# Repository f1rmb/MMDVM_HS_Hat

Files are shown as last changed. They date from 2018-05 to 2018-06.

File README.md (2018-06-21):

# MMDVM_HS_Hat
MMDVM_HS Hat for the Raspberry Pi (Zero)

This project provides a Raspberry Pi Hat for the [MMDVM_HS Hotspot](https://github.com/juribeparada/MMDVM_HS). It was designed for the Raspberry Pi Zero, but should work on any other Pi with the Hat interface. 

First revisions of the board have been built successfully!

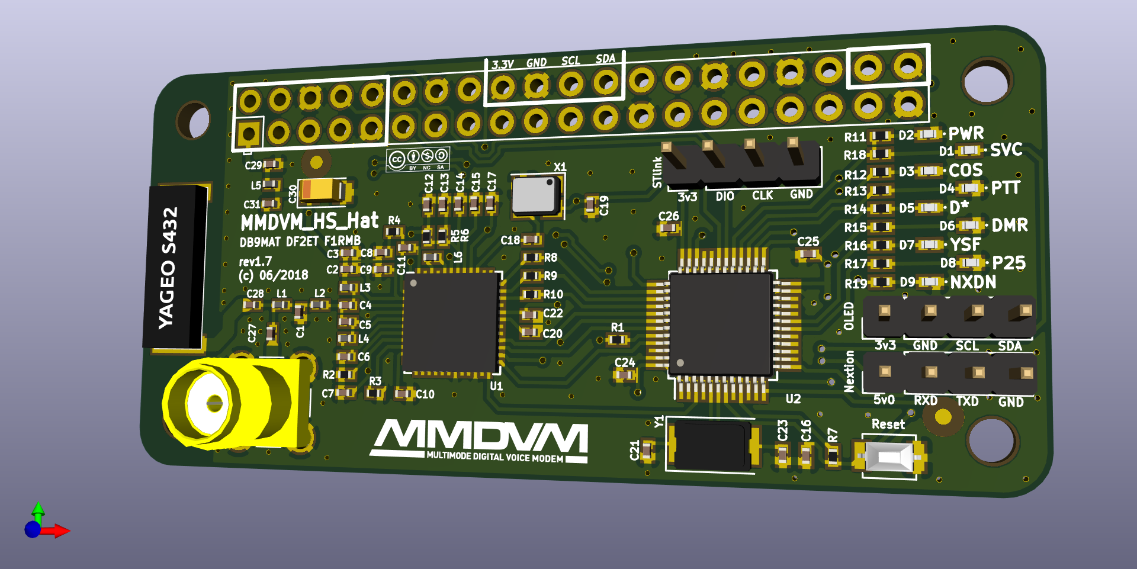
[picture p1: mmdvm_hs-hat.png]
PCB


The PCB is designed in KiCad and the necessary libraries are included. The supplied Gerber files can be used to order PCBs, for example at Elecrow or DirtyPCBs. The board's dimensions are 65x30mm.

__WARNING__
This fork was designed with KiCad 5 RC version (aka development build), opening the PCB file with KiCad 4 will simply fail.

You can order 3 beautiful, purple Revision 1.2 PCBs for $15 at [OSHPark](https://oshpark.com/shared_projects/WaiMw5XE)! 

## 3D printed Cases

Case

Thanks to Toufik, F0DEI we added the ~~sources~~ STL files for a shiny case that you can print with your 3D printer. It may require a little upscaling depending on your printer model. It can carry a Raspberry Pi Zero (W) with MMDVM_HS_Hat (SMA) on top.

<br>
There are also the enclosures, designed by myself, available here https://github.com/f1rmb/MMDVM_HS_Hat-Enclosure

CaseRMB

## Revisions
### Revision 0
This was the first released version that still contains a couple of errors. There is a trace missing between L1 and C1 that needs to be fixed with a small blob of solder or magnet wire. Otherwise the RF connector is not connected to the ADF7021. The GND side of C20 and C22 is not connected to the rest of the board's GND, this needs to be fixed with a little wire to any other GND. CE is connected directly to +3.3V which disallows mode scanning to work. If you just use one mode this is fine, otherwise the connection to the CE pin has to be cut and connected to PC14 on the STM32.

Earlier schematics showed C14 as 1uF. This is wrong and needs to be replaced with 1nF, otherwise the ADF7021 will neither receive nor transmit properly.

With these changes, you can build a fully working MMDVM_HS with the old revision 0 boards

### Revision 1
These boards have "Revision 1" written on them. All bugs found in revision 0 are fixed in this version. Apart from that, the STM32's BOOT0 and RESET pins are connected to GPIOs of the Raspberry Pi. This way, flashing should be possible without manually jumpering BOOT0 and triggering a reset.

Component placement did not change between revisions 0 and 1, therefore any stencils for revision 0 should work for revision 1 boards, too.

### Revision 1.1
Rewired 3v3 line for Nextion display connector to 5v0. Added SERVICE LED for visual heartbeat. Fixed improper labelling on P25 and YSF LEDs. Due to added LEDs this revision requires a new stencil.

### Revision 1.2
This Revision adds support for an optional AN1603-443 ceramic antenna. Insert C27 or C28, depending on what kind of antenna you want to use.

### Revision 1.3
The boot jumper was removed and the STlink header moved to its position. This gave space for another 4-pin header allowing to connect I²C OLED displays. No new stencil needed

### Revision 1.4
The SVC LED has been rotated and thus aligned to the layout of all other LEDs. The RainSun ceramic antenna has been replaced by a model that can be ordered at Mouser. DC line filtering has been added to 3v3 line.

### Revision 1.5
A fith mode LED has been added to the board to show NXDN activity. The two pin headers moved downwards a little. The rev1.4 stencil can be re-used if you manually add solder paste to R19 and D9 afterwards.

### Revision 1.6
Inner RX/TX pins of Nextion connector have been swapped. External VCO inductor L6 was added. This is optional for VHF use. D-Star and DMR LEDs were swapped to flash LEDs in proper scan order :).

### Revision 1.7
I will add the change list later, once the first PCB is assembled and tested :-D (PCB are on their way).

## BOM
* All necessary parts for the Revision 1.1 board can be ordered at Mouser using the following [shopping cart](http://www.mouser.com/ProjectManager/ProjectDetail.aspx?AccessID=780b8eac44)
* All necessary parts for the Revision 1.2 board can be ordered at Mouser using the following [shopping cart](http://www.mouser.com/ProjectManager/ProjectDetail.aspx?AccessID=035e777242)
* There is also a light version of revision 1.2 without the reset switch, 2.54mm headers and SMA connector [Link](http://www.mouser.com/ProjectManager/ProjectDetail.aspx?AccessID=3f7d0256e1)
* The parts for Revision 1.3 board are in this [Mouser cart](http://www.mouser.com/ProjectManager/ProjectDetail.aspx?AccessID=250d76339b) and the light version is [here](http://www.mouser.com/ProjectManager/ProjectDetail.aspx?AccessID=2d533ac53d)
* [Mouser project](http://www.mouser.com/ProjectManager/ProjectDetail.aspx?AccessID=5cab954f40) for MMDVM_HS_Hat revision 1.4
* There is another [Mouser cart for rev 1.5](https://www.mouser.com/ProjectManager/ProjectDetail.aspx?AccessID=5a3e4ae018).
* This is the [rev1.6 cart](https://www.mouser.com/ProjectManager/ProjectDetail.aspx?AccessID=48302f4221) and its [light version](https://www.mouser.com/ProjectManager/ProjectDetail.aspx?AccessID=ac888de33a).
* And this is the [Mouser cart for rev1.7](https://www.mouser.fr/ProjectManager/ProjectDetail.aspx?AccessID=95F1FF1BD5).

Please note that the onboard ceramic antenna is not supplied by Mouser and therefore missing in the carts for revisions up to 1.3.

Either the ADF7021 or the ADF7021-N can be used. Define the proper version in the firmware!

## Firmware Installation

### Compile and upload manually

For specific details about the firmware installation, check [these](https://github.com/juribeparada/MMDVM_HS#build-de-firmware-and-upload-to-zumspot-rpi) instructions. The process is similar to the installation on the ZumSpot Pi. 

Enable the following settings in Config.h:

    #define MMDVM_HS_HAT_REV12
    #define ENABLE_ADF7021
    #define ADF7021_14_7456
    #define STM32_USART1_HOST
    #define ENABLE_SCAN_MODE

Build the firmware:

    make

And finally upload the firmware to the MMDVM_HS_Hat:

    sudo make mmdvm_hs_hat

### Update within Pi-Star

Andy, MW0MWZ was so kind as to add a script which allows for updating the firmware of the MMDVM_HS_Hat within the running Pi-Star system. It uses the pre-compiled binaries from Andy's (CA6JAU) github repository. The update can be done with:

```
$ pistar-zumspotflash hs_hat
```

on the command line.

## Accessoires

* A case for the #MMDVM_HS_Hat can be found at amazon: [Case](https://www.amazon.de/Hochwertiges-schwarzes-auml-uuml-Raspberry/dp/B01FHDXNNU)

* An OLED display also to be found at amazon: [Display](https://www.amazon.de/dp/B01M9JVYIS/ref=cm_sw_r_wa_api_RmZ9zb01APZTV)

## License
This project is released under the Creative Commons Attribution-NonCommercial-ShareAlike 3.0 (CC-BY-NC-SA 3.0, https://creativecommons.org/licenses/by-nc-sa/3.0/) license. You may edit and share it as you like, as long as credit is given and the license is not changed. You can build as many boards for you and your friends as you like and you can even sell it to them to cover your costs, **however it is strictly forbidden to turn this into a commercial product! You are not allowed to build and sell these boards for profit!**

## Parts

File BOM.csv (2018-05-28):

Source: | /home/caudanie/Documents/KiCadProjects/MMDVM_HS_Hat/mmdvm_hs-hat.sch
Date: | Mon 28 May 2018 01:47:52 PM CEST
Tool: | Eeschema 5.0.0-rc2-unknown-da66005~65~ubuntu16.04.1
Generator: | /usr/lib/x86_64-linux-gnu/kicad/plugins/bom_csv_grouped_by_value.py
Component Count: | 76
Individual Components:
Item | Qty | Reference(s) | Value | LibPart | Footprint | Datasheet | MFR | MPN | SPN | SPR | SPURL
 |  | AE1 | CERAMIC_ANTENNA | mmdvm_hs-hat-rescue:Antenna_Dipole-RESCUE-mmdvm_hs-hat | MMDVM:ANT1204 | http://www.mouser.com/ds/2/447/An_SMD_UHF_433_1204_0-595178.pdf | Yageo | ANT1204F002R0433A | 603-ANT1204F002R0433 | Mouser
 |  | C1 | 6p8 | mmdvm_hs-hat-rescue:C-RESCUE-mmdvm_hs-hat | Capacitor_SMD:C_0402_1005Metric | http://www.mouser.com/ds/2/281/c02e-2905.pdf | Murata Electronics | GJM1555C1H6R8BB01D | 81-GJM1555C1H6R8BB1D | Mouser
 |  | C2 | 10n | mmdvm_hs-hat-rescue:C-RESCUE-mmdvm_hs-hat | Capacitor_SMD:C_0402_1005Metric | http://www.mouser.com/ds/2/427/vjw1bcbascomseries-223529.pdf | Vishay / Vitramon | VJ0402Y103KXJCW1BC | 77-VJ0402Y103KXJCBC | Mouser
 |  | C3 | 220p | mmdvm_hs-hat-rescue:C-RESCUE-mmdvm_hs-hat | Capacitor_SMD:C_0402_1005Metric | http://www.mouser.com/ds/2/281/c02e-2905.pdf | Murata Electronics | GRM1555C1H221JA01D | 81-GRM1555C1H221JA01 | Mouser
 |  | C4 | 10p | mmdvm_hs-hat-rescue:C-RESCUE-mmdvm_hs-hat | Capacitor_SMD:C_0402_1005Metric | http://www.mouser.com/ds/2/281/c02e-2905.pdf | Murata Electronics | GRM1555C1E100GA01D | 81-GRM1555C1E100GA1D | Mouser
 |  | C5 | 4p7 | mmdvm_hs-hat-rescue:C-RESCUE-mmdvm_hs-hat | Capacitor_SMD:C_0402_1005Metric | http://www.mouser.com/ds/2/281/c02e-2905.pdf | Murata Electronics | GRM1555C1H4R7CA01D | 81-GRM1555C1H4R7CA1D | Mouser
 |  | C6 | 6p8 | mmdvm_hs-hat-rescue:C-RESCUE-mmdvm_hs-hat | Capacitor_SMD:C_0402_1005Metric | http://www.mouser.com/ds/2/281/c02e-2905.pdf | Murata Electronics | GJM1555C1H6R8BB01D | 81-GJM1555C1H6R8BB1D | Mouser
 |  | C7 | 10n | mmdvm_hs-hat-rescue:C-RESCUE-mmdvm_hs-hat | Capacitor_SMD:C_0402_1005Metric | http://www.mouser.com/ds/2/427/vjw1bcbascomseries-223529.pdf | Vishay / Vitramon | VJ0402Y103KXJCW1BC | 77-VJ0402Y103KXJCBC | Mouser
 |  | C8 | 100n | mmdvm_hs-hat-rescue:C-RESCUE-mmdvm_hs-hat | Capacitor_SMD:C_0402_1005Metric | http://www.mouser.com/ds/2/427/vjw1bcbascomseries-223529.pdf | Vishay / Vitramon | VJ0402V104ZXJCW1BC | 77-VJ0402V104ZXJCBC | Mouser
 |  | C9 | 10n | mmdvm_hs-hat-rescue:C-RESCUE-mmdvm_hs-hat | Capacitor_SMD:C_0402_1005Metric | http://www.mouser.com/ds/2/427/vjw1bcbascomseries-223529.pdf | Vishay / Vitramon | VJ0402Y103KXJCW1BC | 77-VJ0402Y103KXJCBC | Mouser
 |  | C10 | 100n | mmdvm_hs-hat-rescue:C-RESCUE-mmdvm_hs-hat | Capacitor_SMD:C_0402_1005Metric | http://www.mouser.com/ds/2/427/vjw1bcbascomseries-223529.pdf | Vishay / Vitramon | VJ0402V104ZXJCW1BC | 77-VJ0402V104ZXJCBC | Mouser
 |  | C11 | 22n | mmdvm_hs-hat-rescue:C-RESCUE-mmdvm_hs-hat | Capacitor_SMD:C_0402_1005Metric | http://www.mouser.com/ds/2/281/c03e-806517.pdf | Murata Electronics | GCM155R71E223KA55D | 81-GCM155R71E223KA5D | Mouser
 |  | C12 | 470p | mmdvm_hs-hat-rescue:C-RESCUE-mmdvm_hs-hat | Capacitor_SMD:C_0402_1005Metric | http://www.mouser.com/ds/2/281/c02e-2905.pdf | Murata Electronics | GRM155R71H471KA01D | 81-GRM36X471K50 | Mouser
 |  | C13 | 15n | mmdvm_hs-hat-rescue:C-RESCUE-mmdvm_hs-hat | Capacitor_SMD:C_0402_1005Metric | http://www.mouser.com/ds/2/281/c02e-2905.pdf | Murata Electronics | GRM155R71C153KA01D | 81-GRM155R71C153KA1D | Mouser
 |  | C14 | 1n | mmdvm_hs-hat-rescue:C-RESCUE-mmdvm_hs-hat | Capacitor_SMD:C_0402_1005Metric | http://www.mouser.com/ds/2/281/c02e-2905.pdf | Murata Electronics | GRM155R60J102KA01D | 81-GRM155R60J102KA1D | Mouser
 |  | C15 | 100n | mmdvm_hs-hat-rescue:C-RESCUE-mmdvm_hs-hat | Capacitor_SMD:C_0402_1005Metric | http://www.mouser.com/ds/2/427/vjw1bcbascomseries-223529.pdf | Vishay / Vitramon | VJ0402V104ZXJCW1BC | 77-VJ0402V104ZXJCBC | Mouser
 |  | C16 | 100n | mmdvm_hs-hat-rescue:C-RESCUE-mmdvm_hs-hat | Capacitor_SMD:C_0402_1005Metric | http://www.mouser.com/ds/2/427/vjw1bcbascomseries-223529.pdf | Vishay / Vitramon | VJ0402V104ZXJCW1BC | 77-VJ0402V104ZXJCBC | Mouser
 |  | C17 | 10n | mmdvm_hs-hat-rescue:C-RESCUE-mmdvm_hs-hat | Capacitor_SMD:C_0402_1005Metric | http://www.mouser.com/ds/2/427/vjw1bcbascomseries-223529.pdf | Vishay / Vitramon | VJ0402Y103KXJCW1BC | 77-VJ0402Y103KXJCBC | Mouser
 |  | C18 | 22p | mmdvm_hs-hat-rescue:C-RESCUE-mmdvm_hs-hat | Capacitor_SMD:C_0402_1005Metric | http://www.mouser.com/ds/2/40/C0GNP0-Dielectric-951274.pdf | AVX | 04025A220GAT2A | 581-04025A220G | Mouser
 |  | C19 | 10n | mmdvm_hs-hat-rescue:C-RESCUE-mmdvm_hs-hat | Capacitor_SMD:C_0402_1005Metric | http://www.mouser.com/ds/2/427/vjw1bcbascomseries-223529.pdf | Vishay / Vitramon | VJ0402Y103KXJCW1BC | 77-VJ0402Y103KXJCBC | Mouser
 |  | C20 | 100n | mmdvm_hs-hat-rescue:C-RESCUE-mmdvm_hs-hat | Capacitor_SMD:C_0402_1005Metric | http://www.mouser.com/ds/2/427/vjw1bcbascomseries-223529.pdf | Vishay / Vitramon | VJ0402V104ZXJCW1BC | 77-VJ0402V104ZXJCBC | Mouser
 |  | C21 | 20p | mmdvm_hs-hat-rescue:C-RESCUE-mmdvm_hs-hat | Capacitor_SMD:C_0402_1005Metric | http://www.mouser.com/ds/2/281/c02e-2905.pdf | Murata Electronics | GJM1555C1H200FB01D | 81-GJM1555C1H200FB1D | Mouser
 |  | C22 | 10n | mmdvm_hs-hat-rescue:C-RESCUE-mmdvm_hs-hat | Capacitor_SMD:C_0402_1005Metric | http://www.mouser.com/ds/2/427/vjw1bcbascomseries-223529.pdf | Vishay / Vitramon | VJ0402Y103KXJCW1BC | 77-VJ0402Y103KXJCBC | Mouser
 |  | C23 | 20p | mmdvm_hs-hat-rescue:C-RESCUE-mmdvm_hs-hat | Capacitor_SMD:C_0402_1005Metric | http://www.mouser.com/ds/2/281/c02e-2905.pdf | Murata Electronics | GJM1555C1H200FB01D | 81-GJM1555C1H200FB1D | Mouser
 |  | C24 | 100n | mmdvm_hs-hat-rescue:C-RESCUE-mmdvm_hs-hat | Capacitor_SMD:C_0402_1005Metric | http://www.mouser.com/ds/2/427/vjw1bcbascomseries-223529.pdf | Vishay / Vitramon | VJ0402V104ZXJCW1BC | 77-VJ0402V104ZXJCBC | Mouser
 |  | C25 | 100n | mmdvm_hs-hat-rescue:C-RESCUE-mmdvm_hs-hat | Capacitor_SMD:C_0402_1005Metric | http://www.mouser.com/ds/2/427/vjw1bcbascomseries-223529.pdf | Vishay / Vitramon | VJ0402V104ZXJCW1BC | 77-VJ0402V104ZXJCBC | Mouser
 |  | C26 | 100n | mmdvm_hs-hat-rescue:C-RESCUE-mmdvm_hs-hat | Capacitor_SMD:C_0402_1005Metric | http://www.mouser.com/ds/2/427/vjw1bcbascomseries-223529.pdf | Vishay / Vitramon | VJ0402V104ZXJCW1BC | 77-VJ0402V104ZXJCBC | Mouser
 |  | C27 | 100n | mmdvm_hs-hat-rescue:C-RESCUE-mmdvm_hs-hat | Capacitor_SMD:C_0402_1005Metric | http://www.mouser.com/ds/2/427/vjw1bcbascomseries-223529.pdf | Vishay / Vitramon | VJ0402V104ZXJCW1BC | 77-VJ0402V104ZXJCBC | Mouser
 |  | C28 | 100n | mmdvm_hs-hat-rescue:C-RESCUE-mmdvm_hs-hat | Capacitor_SMD:C_0402_1005Metric | http://www.mouser.com/ds/2/427/vjw1bcbascomseries-223529.pdf | Vishay / Vitramon | VJ0402V104ZXJCW1BC | 77-VJ0402V104ZXJCBC | Mouser
 |  | C29 | 100n | mmdvm_hs-hat-rescue:C-RESCUE-mmdvm_hs-hat | Capacitor_SMD:C_0402_1005Metric | http://www.mouser.com/ds/2/427/vjw1bcbascomseries-223529.pdf | Vishay / Vitramon | VJ0402V104ZXJCW1BC | 77-VJ0402V104ZXJCBC | Mouser
 |  | C30 | 10u/10V | mmdvm_hs-hat-rescue:CP-RESCUE-mmdvm_hs-hat | Capacitor_Tantalum_SMD:CP_EIA-3216-18_Kemet-A | http://www.mouser.com/ds/2/40/f93-776559.pdf | AVX | F931A106KAA | 647-F931A106KAA | Mouser
 |  | C31 | 10u | mmdvm_hs-hat-rescue:C-RESCUE-mmdvm_hs-hat | Capacitor_SMD:C_0402_1005Metric | http://www.mouser.com/ds/2/281/c02e-2905.pdf | Murata Electronics | GRJ155R60J106ME11D | 81-GRJ155R60J106ME1D | Mouser
 |  | D1 | red | mmdvm_hs-hat-rescue:LED-RESCUE-mmdvm_hs-hat | LED_SMD:LED_0402_1005Metric | http://www.mouser.com/ds/2/216/APHHS1005SURCK-32322.pdf | Kingbright | APHHS1005SURCK | 604-APHHS1005SURCK | Mouser
 |  | D2 | green | mmdvm_hs-hat-rescue:LED-RESCUE-mmdvm_hs-hat | LED_SMD:LED_0402_1005Metric | http://www.mouser.com/ds/2/216/APHHS1005CGCK-38896.pdf | Kingbright | APHHS1005CGCK | 604-APHHS1005CGCK | Mouser
 |  | D3 | yellow | mmdvm_hs-hat-rescue:LED-RESCUE-mmdvm_hs-hat | LED_SMD:LED_0402_1005Metric | http://www.mouser.com/ds/2/216/APG1005SYC-T-315808.pdf | Kingbright | APG1005SYC-T | 604-APG1005SYCT | Mouser
 |  | D4 | red | mmdvm_hs-hat-rescue:LED-RESCUE-mmdvm_hs-hat | LED_SMD:LED_0402_1005Metric | http://www.mouser.com/ds/2/216/APHHS1005SURCK-32322.pdf | Kingbright | APHHS1005SURCK | 604-APHHS1005SURCK | Mouser
 |  | D5 | green | mmdvm_hs-hat-rescue:LED-RESCUE-mmdvm_hs-hat | LED_SMD:LED_0402_1005Metric | http://www.mouser.com/ds/2/216/APG1005SYC-T-315808.pdf | Kingbright | APG1005SYC-T | 604-APG1005SYCT | Mouser
 |  | D6 | yellow | mmdvm_hs-hat-rescue:LED-RESCUE-mmdvm_hs-hat | LED_SMD:LED_0402_1005Metric | http://www.mouser.com/ds/2/216/APHHS1005CGCK-38896.pdf | Kingbright | APHHS1005CGCK | 604-APHHS1005CGCK | Mouser
 |  | D7 | amber | mmdvm_hs-hat-rescue:LED-RESCUE-mmdvm_hs-hat | LED_SMD:LED_0402_1005Metric | https://www.mouser.de/kingbright-minikin-air-leds | Kingbright | APG1005SEC-T | 604-APG1005SECT | Mouser
 |  | D8 | red | mmdvm_hs-hat-rescue:LED-RESCUE-mmdvm_hs-hat | LED_SMD:LED_0402_1005Metric | http://www.mouser.com/ds/2/216/APHHS1005SURCK-32322.pdf | Kingbright | APHHS1005SURCK | 604-APHHS1005SURCK | Mouser
 |  | D9 | blue | mmdvm_hs-hat-rescue:LED-RESCUE-mmdvm_hs-hat | LED_SMD:LED_0402_1005Metric | https://www.mouser.com/ds/2/216/APHHS1005QBC-D-54846.pdf | Kingbright | APHHS1005QBC/D | 604-APHHS1005QBCD | Mouser
 |  | L1 | 22n | mmdvm_hs-hat-rescue:L-RESCUE-mmdvm_hs-hat | Inductor_SMD:L_0402_1005Metric | http://www.mouser.com/ds/2/281/JELF243A-0140-937123.pdf | Murata Electronics | LQW15CA22NJ00D | 81-LQW15CA22NJ00D | Mouser
 |  | L2 | 20n | mmdvm_hs-hat-rescue:L-RESCUE-mmdvm_hs-hat | Inductor_SMD:L_0402_1005Metric | http://www.mouser.com/ds/2/418/NG_CD_1624112_BA1-656883.pdf | TE Connectivity / Sigma Inductors | 36501E20NJTDG | 279-36501E20NJTDG | Mouser
 |  | L3 | 13n | mmdvm_hs-hat-rescue:L-RESCUE-mmdvm_hs-hat | Inductor_SMD:L_0402_1005Metric | http://www.mouser.com/ds/2/281/murata_inductors-1186262.pdf | Murata Electronics | LQW15AN13NG80D | 81-LQW15AN13NG80D | Mouser
 |  | L4 | 27n | mmdvm_hs-hat-rescue:L-RESCUE-mmdvm_hs-hat | Inductor_SMD:L_0402_1005Metric | http://www.mouser.com/ds/2/281/murata_inductors-1186262.pdf | Murata Electronics | LQW15AN27NG80D | 81-LQW15AN27NG80D | Mouser
 |  | L5 | 10u | mmdvm_hs-hat-rescue:L-RESCUE-mmdvm_hs-hat | Inductor_SMD:L_0402_1005Metric | http://www.mouser.com/ds/2/445/74279277-372706.pdf | Wurth Electronics | 74279277 | 710-74279277 | Mouser
 |  | L6 | 18n | mmdvm_hs-hat-rescue:L-RESCUE-mmdvm_hs-hat | Inductor_SMD:L_0402_1005Metric | https://www.mouser.com/ds/2/418/NG_CS_1309350_PASSIVE_COMPONENT_0807-1236213.pdf | TE Connectivity / Sigma Inductors | 36501E18NJTDG | 279-36501E18NJTDG | Mouser
 |  | P1 | I2C | mmdvm_hs-hat-rescue:CONN_01X04-RESCUE-mmdvm_hs-hat | Connector_PinHeader_2.54mm:PinHeader_1x04_P2.54mm_Vertical | http://www.mouser.com/ds/2/418/NG_CD_826629_AA_baseFilename-683270.pdf | TE Connectivity / AMP | 826629-4 | 571-826629-4 | Mouser
 |  | P2 | DISPLAY | mmdvm_hs-hat-rescue:CONN_01X04-RESCUE-mmdvm_hs-hat | Connector_PinHeader_2.54mm:PinHeader_1x04_P2.54mm_Vertical | http://www.mouser.com/ds/2/418/NG_CD_826629_AA_baseFilename-683270.pdf | TE Connectivity / AMP | 826629-4 | 571-826629-4 | Mouser
 |  | P3 | SMA | mmdvm_hs-hat-rescue:CONN_01X02-RESCUE-mmdvm_hs-hat | Connectors:SMA_THT_Jack_Straight | http://www.mouser.com/ds/2/18/C901-144-8RFX-710432.pdf | TE Connectivity | 5-1814832-1 | 571-5-1814832-1 | Mouser
 |  | P4 | STLINK | mmdvm_hs-hat-rescue:CONN_01X04-RESCUE-mmdvm_hs-hat | Connector_PinHeader_2.54mm:PinHeader_1x04_P2.54mm_Vertical | http://www.mouser.com/ds/2/418/NG_CD_826629_AA_baseFilename-683270.pdf | TE Connectivity / AMP | 826629-4 | 571-826629-4 | Mouser
 |  | PI1 | RPI-ZERO | RPI-Zero:RPI-ZERO | pizero:RPI-Zero-RASPBERRYPI_BASTELSTUBE_V13_RASPI_BOARD_B+_FULL | http://www.mouser.com/ds/2/181/M20-783-351164.pdf | Harwin | M20-7832046 | 855-M20-7832046 | Mouser
 |  | R1 | 10k | mmdvm_hs-hat-rescue:R-RESCUE-mmdvm_hs-hat | Resistor_SMD:R_0402_1005Metric | http://www.mouser.com/ds/2/427/dcrcwe3-109170.pdf | Vishay | CRCW040210K0FKED | 71-CRCW0402-10K-E3 | Mouser
 |  | R2 | 1k1 | mmdvm_hs-hat-rescue:R-RESCUE-mmdvm_hs-hat | Resistor_SMD:R_0402_1005Metric | http://www.mouser.com/ds/2/392/susumu_RR_Data_Sheet-358748.pdf | Susumu | RR0510P-112-D | 754-RR0510P-112D | Mouser
 |  | R3 | 3k8 | mmdvm_hs-hat-rescue:R-RESCUE-mmdvm_hs-hat | Resistor_SMD:R_0402_1005Metric | http://www.mouser.com/ds/2/392/susumu_RR_Data_Sheet-358748.pdf | Susumu | RR0510P-3831-D | 754-RR0510P-3831D | Mouser
 |  | R4 | 3r9 | mmdvm_hs-hat-rescue:R-RESCUE-mmdvm_hs-hat | Resistor_SMD:R_0402_1005Metric | http://www.mouser.com/ds/2/427/dcrcwe3-109170.pdf | Vishay | CRCW04023R90JNED | 71-CRCW0402J-3.9-E3 | Mouser
 |  | R5 | 560 | mmdvm_hs-hat-rescue:R-RESCUE-mmdvm_hs-hat | Resistor_SMD:R_0402_1005Metric | http://www.mouser.com/ds/2/315/AOA0000C237-1100991.pdf | Panasonic | ERA-2AEB561X | 667-ERA-2AEB561X | Mouser
 |  | R6 | 270 | mmdvm_hs-hat-rescue:R-RESCUE-mmdvm_hs-hat | Resistor_SMD:R_0402_1005Metric | http://www.mouser.com/ds/2/315/AOA0000C237-1100991.pdf | Panasonic | ERA-2AEB271X | 667-ERA-2AEB271X | Mouser
 |  | R7 | 10k | mmdvm_hs-hat-rescue:R-RESCUE-mmdvm_hs-hat | Resistor_SMD:R_0402_1005Metric | http://www.mouser.com/ds/2/427/dcrcwe3-109170.pdf | Vishay | CRCW040210K0FKED | 71-CRCW0402-10K-E3 | Mouser
 |  | R8 | 1k | mmdvm_hs-hat-rescue:R-RESCUE-mmdvm_hs-hat | Resistor_SMD:R_0402_1005Metric | http://www.mouser.com/ds/2/315/AOA0000C291-1101061.pdf | Panasonic | ERJ-PA2D1001X | 667-ERJ-PA2D1001X | Mouser
 |  | R9 | 1k | mmdvm_hs-hat-rescue:R-RESCUE-mmdvm_hs-hat | Resistor_SMD:R_0402_1005Metric | http://www.mouser.com/ds/2/315/AOA0000C291-1101061.pdf | Panasonic | ERJ-PA2D1001X | 667-ERJ-PA2D1001X | Mouser
 |  | R10 | 1k | mmdvm_hs-hat-rescue:R-RESCUE-mmdvm_hs-hat | Resistor_SMD:R_0402_1005Metric | http://www.mouser.com/ds/2/315/AOA0000C291-1101061.pdf | Panasonic | ERJ-PA2D1001X | 667-ERJ-PA2D1001X | Mouser
 |  | R11 | 1k | mmdvm_hs-hat-rescue:R-RESCUE-mmdvm_hs-hat | Resistor_SMD:R_0402_1005Metric | http://www.mouser.com/ds/2/315/AOA0000C291-1101061.pdf | Panasonic | ERJ-PA2D1001X | 667-ERJ-PA2D1001X | Mouser
 |  | R12 | 1k | mmdvm_hs-hat-rescue:R-RESCUE-mmdvm_hs-hat | Resistor_SMD:R_0402_1005Metric | http://www.mouser.com/ds/2/315/AOA0000C291-1101061.pdf | Panasonic | ERJ-PA2D1001X | 667-ERJ-PA2D1001X | Mouser
 |  | R13 | 1k | mmdvm_hs-hat-rescue:R-RESCUE-mmdvm_hs-hat | Resistor_SMD:R_0402_1005Metric | http://www.mouser.com/ds/2/315/AOA0000C291-1101061.pdf | Panasonic | ERJ-PA2D1001X | 667-ERJ-PA2D1001X | Mouser
 |  | R14 | 1k | mmdvm_hs-hat-rescue:R-RESCUE-mmdvm_hs-hat | Resistor_SMD:R_0402_1005Metric | http://www.mouser.com/ds/2/315/AOA0000C291-1101061.pdf | Panasonic | ERJ-PA2D1001X | 667-ERJ-PA2D1001X | Mouser
 |  | R15 | 1k | mmdvm_hs-hat-rescue:R-RESCUE-mmdvm_hs-hat | Resistor_SMD:R_0402_1005Metric | http://www.mouser.com/ds/2/315/AOA0000C291-1101061.pdf | Panasonic | ERJ-PA2D1001X | 667-ERJ-PA2D1001X | Mouser
 |  | R16 | 1k | mmdvm_hs-hat-rescue:R-RESCUE-mmdvm_hs-hat | Resistor_SMD:R_0402_1005Metric | http://www.mouser.com/ds/2/315/AOA0000C291-1101061.pdf | Panasonic | ERJ-PA2D1001X | 667-ERJ-PA2D1001X | Mouser
 |  | R17 | 1k | mmdvm_hs-hat-rescue:R-RESCUE-mmdvm_hs-hat | Resistor_SMD:R_0402_1005Metric | http://www.mouser.com/ds/2/315/AOA0000C291-1101061.pdf | Panasonic | ERJ-PA2D1001X | 667-ERJ-PA2D1001X | Mouser
 |  | R18 | 1k | mmdvm_hs-hat-rescue:R-RESCUE-mmdvm_hs-hat | Resistor_SMD:R_0402_1005Metric | http://www.mouser.com/ds/2/315/AOA0000C291-1101061.pdf | Panasonic | ERJ-PA2D1001X | 667-ERJ-PA2D1001X | Mouser
 |  | R19 | 1k | mmdvm_hs-hat-rescue:R-RESCUE-mmdvm_hs-hat | Resistor_SMD:R_0402_1005Metric | http://www.mouser.com/ds/2/315/AOA0000C291-1101061.pdf | Panasonic | ERJ-PA2D1001X | 667-ERJ-PA2D1001X | Mouser
 |  | SW1 | DNI | mmdvm_hs-hat-rescue:SW_DIP_x01-RESCUE-mmdvm_hs-hat | Buttons_Switches_SMD:SW_SPST_B3U-1000P | http://www.mouser.com/ds/2/307/en-b3u-3615.pdf | Omron Electronics | B3U-1000P | 653-B3U-1000P | Mouser
 |  | U1 | ADF7021 | adf7021:ADF7021 | Housings_DFN_QFN:QFN-48-1EP_7x7mm_Pitch0.5mm | http://www.mouser.com/ds/2/609/ADF7021-878461.pdf | Analog Devices | ADF7021BCPZ | 584-ADF7021BCPZ | Mouser
 |  | U2 | STM32F103C8T6 | stm32f103c8t6:STM32F103C8T6 | Housings_QFP:LQFP-48_7x7mm_Pitch0.5mm | http://www.mouser.com/ds/2/389/stm32f103c8-956229.pdf | STMicroelectronics | STM32F103C8T6 | 511-STM32F103C8T6 | Mouser
 |  | X1 | TCXO | mmdvm_hs-hat-rescue:TCXO_DFAS11-RESCUE-mmdvm_hs-hat | Crystals:Crystal_SMD_3225-4pin_3.2x2.5mm | http://www.mouser.com/ds/2/122/ECS-TXO-3225-608196.pdf | ECS | ECS-TXO-3225-147.4-TR | 520-TXO-3225-14.74T | Mouser
 |  | Y1 | 8MHz | mmdvm_hs-hat-rescue:Crystal-RESCUE-mmdvm_hs-hat | Crystals:Crystal_SMD_Abracon_ABM3-2pin_5.0x3.2mm | http://www.mouser.com/ds/2/3/abm3-47699.pdf | ABRACON | ABM3-8.000MHz-D2Y-T | 815-ABM3-8-D2Y-T | Mouser
Collated Components:
Item | Qty | Reference(s) | Value | LibPart | Footprint | Datasheet | MFR | MPN | SPN | SPR | SPURL
1 | 1 | AE1 | CERAMIC_ANTENNA | mmdvm_hs-hat-rescue:Antenna_Dipole-RESCUE-mmdvm_hs-hat | MMDVM:ANT1204 | http://www.mouser.com/ds/2/447/An_SMD_UHF_433_1204_0-595178.pdf | Yageo | ANT1204F002R0433A | 603-ANT1204F002R0433 | Mouser
2 | 2 | C1, C6 | 6p8 | mmdvm_hs-hat-rescue:C-RESCUE-mmdvm_hs-hat | Capacitor_SMD:C_0402_1005Metric | http://www.mouser.com/ds/2/281/c02e-2905.pdf | Murata Electronics | GJM1555C1H6R8BB01D | 81-GJM1555C1H6R8BB1D | Mouser
3 | 6 | C2, C7, C9, C17, C19, C22 | 10n | mmdvm_hs-hat-rescue:C-RESCUE-mmdvm_hs-hat | Capacitor_SMD:C_0402_1005Metric | http://www.mouser.com/ds/2/427/vjw1bcbascomseries-223529.pdf | Vishay / Vitramon | VJ0402Y103KXJCW1BC | 77-VJ0402Y103KXJCBC | Mouser
4 | 1 | C3 | 220p | mmdvm_hs-hat-rescue:C-RESCUE-mmdvm_hs-hat | Capacitor_SMD:C_0402_1005Metric | http://www.mouser.com/ds/2/281/c02e-2905.pdf | Murata Electronics | GRM1555C1H221JA01D | 81-GRM1555C1H221JA01 | Mouser
5 | 1 | C4 | 10p | mmdvm_hs-hat-rescue:C-RESCUE-mmdvm_hs-hat | Capacitor_SMD:C_0402_1005Metric | http://www.mouser.com/ds/2/281/c02e-2905.pdf | Murata Electronics | GRM1555C1E100GA01D | 81-GRM1555C1E100GA1D | Mouser
6 | 1 | C5 | 4p7 | mmdvm_hs-hat-rescue:C-RESCUE-mmdvm_hs-hat | Capacitor_SMD:C_0402_1005Metric | http://www.mouser.com/ds/2/281/c02e-2905.pdf | Murata Electronics | GRM1555C1H4R7CA01D | 81-GRM1555C1H4R7CA1D | Mouser
7 | 11 | C8, C10, C15, C16, C20, C24, C25, C26, C27, C28, C29 | 100n | mmdvm_hs-hat-rescue:C-RESCUE-mmdvm_hs-hat | Capacitor_SMD:C_0402_1005Metric | http://www.mouser.com/ds/2/427/vjw1bcbascomseries-223529.pdf | Vishay / Vitramon | VJ0402V104ZXJCW1BC | 77-VJ0402V104ZXJCBC | Mouser
8 | 1 | C11 | 22n | mmdvm_hs-hat-rescue:C-RESCUE-mmdvm_hs-hat | Capacitor_SMD:C_0402_1005Metric | http://www.mouser.com/ds/2/281/c03e-806517.pdf | Murata Electronics | GCM155R71E223KA55D | 81-GCM155R71E223KA5D | Mouser
9 | 1 | C12 | 470p | mmdvm_hs-hat-rescue:C-RESCUE-mmdvm_hs-hat | Capacitor_SMD:C_0402_1005Metric | http://www.mouser.com/ds/2/281/c02e-2905.pdf | Murata Electronics | GRM155R71H471KA01D | 81-GRM36X471K50 | Mouser
10 | 1 | C13 | 15n | mmdvm_hs-hat-rescue:C-RESCUE-mmdvm_hs-hat | Capacitor_SMD:C_0402_1005Metric | http://www.mouser.com/ds/2/281/c02e-2905.pdf | Murata Electronics | GRM155R71C153KA01D | 81-GRM155R71C153KA1D | Mouser
11 | 1 | C14 | 1n | mmdvm_hs-hat-rescue:C-RESCUE-mmdvm_hs-hat | Capacitor_SMD:C_0402_1005Metric | http://www.mouser.com/ds/2/281/c02e-2905.pdf | Murata Electronics | GRM155R60J102KA01D | 81-GRM155R60J102KA1D | Mouser
12 | 1 | C18 | 22p | mmdvm_hs-hat-rescue:C-RESCUE-mmdvm_hs-hat | Capacitor_SMD:C_0402_1005Metric | http://www.mouser.com/ds/2/40/C0GNP0-Dielectric-951274.pdf | AVX | 04025A220GAT2A | 581-04025A220G | Mouser
13 | 2 | C21, C23 | 20p | mmdvm_hs-hat-rescue:C-RESCUE-mmdvm_hs-hat | Capacitor_SMD:C_0402_1005Metric | http://www.mouser.com/ds/2/281/c02e-2905.pdf | Murata Electronics | GJM1555C1H200FB01D | 81-GJM1555C1H200FB1D | Mouser
14 | 1 | C30 | 10u/10V | mmdvm_hs-hat-rescue:CP-RESCUE-mmdvm_hs-hat | Capacitor_Tantalum_SMD:CP_EIA-3216-18_Kemet-A | http://www.mouser.com/ds/2/40/f93-776559.pdf | AVX | F931A106KAA | 647-F931A106KAA | Mouser
15 | 1 | C31 | 10u | mmdvm_hs-hat-rescue:C-RESCUE-mmdvm_hs-hat | Capacitor_SMD:C_0402_1005Metric | http://www.mouser.com/ds/2/281/c02e-2905.pdf | Murata Electronics | GRJ155R60J106ME11D | 81-GRJ155R60J106ME1D | Mouser
16 | 3 | D1, D4, D8 | red | mmdvm_hs-hat-rescue:LED-RESCUE-mmdvm_hs-hat | LED_SMD:LED_0402_1005Metric | http://www.mouser.com/ds/2/216/APHHS1005SURCK-32322.pdf | Kingbright | APHHS1005SURCK | 604-APHHS1005SURCK | Mouser
17 | 2 | D2, D5 | green | mmdvm_hs-hat-rescue:LED-RESCUE-mmdvm_hs-hat | LED_SMD:LED_0402_1005Metric | http://www.mouser.com/ds/2/216/APHHS1005CGCK-38896.pdf | Kingbright | APHHS1005CGCK | 604-APHHS1005CGCK | Mouser
18 | 2 | D3, D6 | yellow | mmdvm_hs-hat-rescue:LED-RESCUE-mmdvm_hs-hat | LED_SMD:LED_0402_1005Metric | http://www.mouser.com/ds/2/216/APG1005SYC-T-315808.pdf | Kingbright | APG1005SYC-T | 604-APG1005SYCT | Mouser
19 | 1 | D7 | amber | mmdvm_hs-hat-rescue:LED-RESCUE-mmdvm_hs-hat | LED_SMD:LED_0402_1005Metric | https://www.mouser.de/kingbright-minikin-air-leds | Kingbright | APG1005SEC-T | 604-APG1005SECT | Mouser
20 | 1 | D9 | blue | mmdvm_hs-hat-rescue:LED-RESCUE-mmdvm_hs-hat | LED_SMD:LED_0402_1005Metric | https://www.mouser.com/ds/2/216/APHHS1005QBC-D-54846.pdf | Kingbright | APHHS1005QBC/D | 604-APHHS1005QBCD | Mouser
21 | 1 | L1 | 22n | mmdvm_hs-hat-rescue:L-RESCUE-mmdvm_hs-hat | Inductor_SMD:L_0402_1005Metric | http://www.mouser.com/ds/2/281/JELF243A-0140-937123.pdf | Murata Electronics | LQW15CA22NJ00D | 81-LQW15CA22NJ00D | Mouser
22 | 1 | L2 | 20n | mmdvm_hs-hat-rescue:L-RESCUE-mmdvm_hs-hat | Inductor_SMD:L_0402_1005Metric | http://www.mouser.com/ds/2/418/NG_CD_1624112_BA1-656883.pdf | TE Connectivity / Sigma Inductors | 36501E20NJTDG | 279-36501E20NJTDG | Mouser
23 | 1 | L3 | 13n | mmdvm_hs-hat-rescue:L-RESCUE-mmdvm_hs-hat | Inductor_SMD:L_0402_1005Metric | http://www.mouser.com/ds/2/281/murata_inductors-1186262.pdf | Murata Electronics | LQW15AN13NG80D | 81-LQW15AN13NG80D | Mouser
24 | 1 | L4 | 27n | mmdvm_hs-hat-rescue:L-RESCUE-mmdvm_hs-hat | Inductor_SMD:L_0402_1005Metric | http://www.mouser.com/ds/2/281/murata_inductors-1186262.pdf | Murata Electronics | LQW15AN27NG80D | 81-LQW15AN27NG80D | Mouser
25 | 1 | L5 | 10u | mmdvm_hs-hat-rescue:L-RESCUE-mmdvm_hs-hat | Inductor_SMD:L_0402_1005Metric | http://www.mouser.com/ds/2/445/74279277-372706.pdf | Wurth Electronics | 74279277 | 710-74279277 | Mouser
26 | 1 | L6 | 18n | mmdvm_hs-hat-rescue:L-RESCUE-mmdvm_hs-hat | Inductor_SMD:L_0402_1005Metric | https://www.mouser.com/ds/2/418/NG_CS_1309350_PASSIVE_COMPONENT_0807-1236213.pdf | TE Connectivity / Sigma Inductors | 36501E18NJTDG | 279-36501E18NJTDG | Mouser
27 | 1 | P1 | I2C | mmdvm_hs-hat-rescue:CONN_01X04-RESCUE-mmdvm_hs-hat | Connector_PinHeader_2.54mm:PinHeader_1x04_P2.54mm_Vertical | http://www.mouser.com/ds/2/418/NG_CD_826629_AA_baseFilename-683270.pdf | TE Connectivity / AMP | 826629-4 | 571-826629-4 | Mouser
28 | 1 | P2 | DISPLAY | mmdvm_hs-hat-rescue:CONN_01X04-RESCUE-mmdvm_hs-hat | Connector_PinHeader_2.54mm:PinHeader_1x04_P2.54mm_Vertical | http://www.mouser.com/ds/2/418/NG_CD_826629_AA_baseFilename-683270.pdf | TE Connectivity / AMP | 826629-4 | 571-826629-4 | Mouser
29 | 1 | P3 | SMA | mmdvm_hs-hat-rescue:CONN_01X02-RESCUE-mmdvm_hs-hat | Connectors:SMA_THT_Jack_Straight | http://www.mouser.com/ds/2/18/C901-144-8RFX-710432.pdf | TE Connectivity | 5-1814832-1 | 571-5-1814832-1 | Mouser
30 | 1 | P4 | STLINK | mmdvm_hs-hat-rescue:CONN_01X04-RESCUE-mmdvm_hs-hat | Connector_PinHeader_2.54mm:PinHeader_1x04_P2.54mm_Vertical | http://www.mouser.com/ds/2/418/NG_CD_826629_AA_baseFilename-683270.pdf | TE Connectivity / AMP | 826629-4 | 571-826629-4 | Mouser
31 | 1 | PI1 | RPI-ZERO | RPI-Zero:RPI-ZERO | pizero:RPI-Zero-RASPBERRYPI_BASTELSTUBE_V13_RASPI_BOARD_B+_FULL | http://www.mouser.com/ds/2/181/M20-783-351164.pdf | Harwin | M20-7832046 | 855-M20-7832046 | Mouser
32 | 2 | R1, R7 | 10k | mmdvm_hs-hat-rescue:R-RESCUE-mmdvm_hs-hat | Resistor_SMD:R_0402_1005Metric | http://www.mouser.com/ds/2/427/dcrcwe3-109170.pdf | Vishay | CRCW040210K0FKED | 71-CRCW0402-10K-E3 | Mouser
33 | 1 | R2 | 1k1 | mmdvm_hs-hat-rescue:R-RESCUE-mmdvm_hs-hat | Resistor_SMD:R_0402_1005Metric | http://www.mouser.com/ds/2/392/susumu_RR_Data_Sheet-358748.pdf | Susumu | RR0510P-112-D | 754-RR0510P-112D | Mouser
34 | 1 | R3 | 3k8 | mmdvm_hs-hat-rescue:R-RESCUE-mmdvm_hs-hat | Resistor_SMD:R_0402_1005Metric | http://www.mouser.com/ds/2/392/susumu_RR_Data_Sheet-358748.pdf | Susumu | RR0510P-3831-D | 754-RR0510P-3831D | Mouser
35 | 1 | R4 | 3r9 | mmdvm_hs-hat-rescue:R-RESCUE-mmdvm_hs-hat | Resistor_SMD:R_0402_1005Metric | http://www.mouser.com/ds/2/427/dcrcwe3-109170.pdf | Vishay | CRCW04023R90JNED | 71-CRCW0402J-3.9-E3 | Mouser
36 | 1 | R5 | 560 | mmdvm_hs-hat-rescue:R-RESCUE-mmdvm_hs-hat | Resistor_SMD:R_0402_1005Metric | http://www.mouser.com/ds/2/315/AOA0000C237-1100991.pdf | Panasonic | ERA-2AEB561X | 667-ERA-2AEB561X | Mouser
37 | 1 | R6 | 270 | mmdvm_hs-hat-rescue:R-RESCUE-mmdvm_hs-hat | Resistor_SMD:R_0402_1005Metric | http://www.mouser.com/ds/2/315/AOA0000C237-1100991.pdf | Panasonic | ERA-2AEB271X | 667-ERA-2AEB271X | Mouser
38 | 12 | R8, R9, R10, R11, R12, R13, R14, R15, R16, R17, R18, R19 | 1k | mmdvm_hs-hat-rescue:R-RESCUE-mmdvm_hs-hat | Resistor_SMD:R_0402_1005Metric | http://www.mouser.com/ds/2/315/AOA0000C291-1101061.pdf | Panasonic | ERJ-PA2D1001X | 667-ERJ-PA2D1001X | Mouser
39 | 1 | SW1 | DNI | mmdvm_hs-hat-rescue:SW_DIP_x01-RESCUE-mmdvm_hs-hat | Buttons_Switches_SMD:SW_SPST_B3U-1000P | http://www.mouser.com/ds/2/307/en-b3u-3615.pdf | Omron Electronics | B3U-1000P | 653-B3U-1000P | Mouser
40 | 1 | U1 | ADF7021 | adf7021:ADF7021 | Housings_DFN_QFN:QFN-48-1EP_7x7mm_Pitch0.5mm | http://www.mouser.com/ds/2/609/ADF7021-878461.pdf | Analog Devices | ADF7021BCPZ | 584-ADF7021BCPZ | Mouser
41 | 1 | U2 | STM32F103C8T6 | stm32f103c8t6:STM32F103C8T6 | Housings_QFP:LQFP-48_7x7mm_Pitch0.5mm | http://www.mouser.com/ds/2/389/stm32f103c8-956229.pdf | STMicroelectronics | STM32F103C8T6 | 511-STM32F103C8T6 | Mouser
42 | 1 | X1 | TCXO | mmdvm_hs-hat-rescue:TCXO_DFAS11-RESCUE-mmdvm_hs-hat | Crystals:Crystal_SMD_3225-4pin_3.2x2.5mm | http://www.mouser.com/ds/2/122/ECS-TXO-3225-608196.pdf | ECS | ECS-TXO-3225-147.4-TR | 520-TXO-3225-14.74T | Mouser
43 | 1 | Y1 | 8MHz | mmdvm_hs-hat-rescue:Crystal-RESCUE-mmdvm_hs-hat | Crystals:Crystal_SMD_Abracon_ABM3-2pin_5.0x3.2mm | http://www.mouser.com/ds/2/3/abm3-47699.pdf | ABRACON | ABM3-8.000MHz-D2Y-T | 815-ABM3-8-D2Y-T | Mouser

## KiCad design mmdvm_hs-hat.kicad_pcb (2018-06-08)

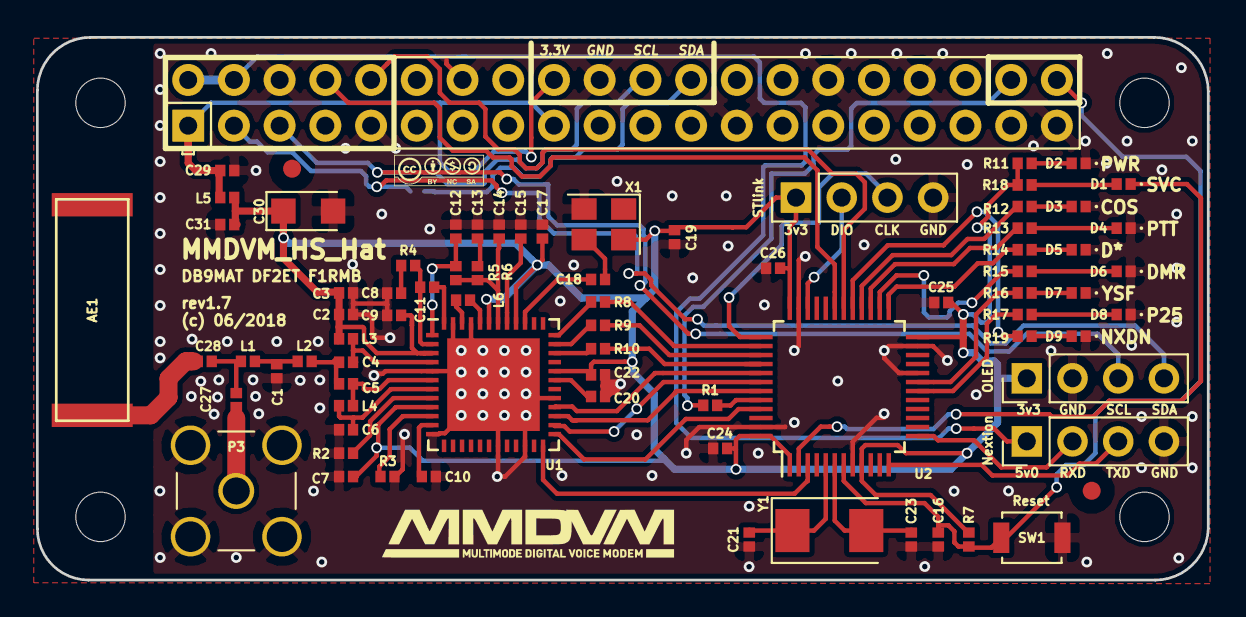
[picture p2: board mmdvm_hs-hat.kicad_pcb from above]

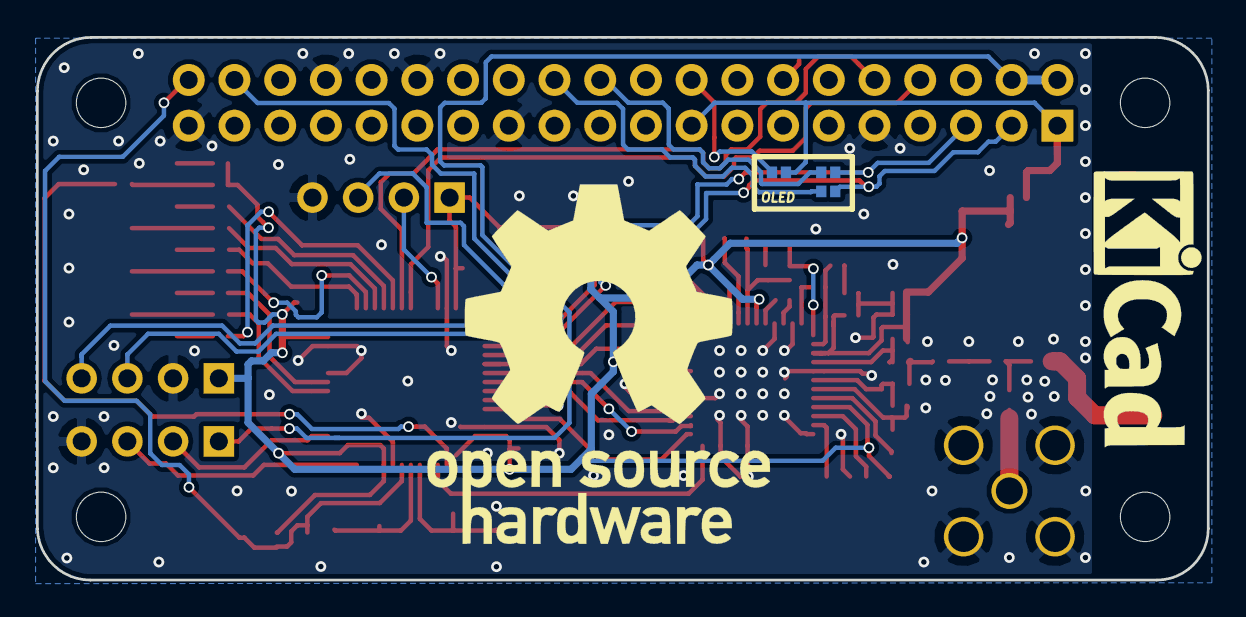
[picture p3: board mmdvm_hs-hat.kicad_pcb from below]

Board: 2 copper layers, 65.1 x 30.2 mm, 79 parts (3 on the bottom side), 71 nets.

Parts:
AE1: CERAMIC_ANTENNA; ANT1204
C1, C6: 6p8; C_0402_1005Metric
C2, C7, C9, C17, C19, C22: 10n; C_0402_1005Metric
C3: 220p; C_0402_1005Metric
C4: 10p; C_0402_1005Metric
C5: 4p7; C_0402_1005Metric
C8, C10, C15, C16, C20, C24, C25, C26, C27, C28, C29: 100n; C_0402_1005Metric
C11: 22n; C_0402_1005Metric
C12: 470p; C_0402_1005Metric
C13: 15n; C_0402_1005Metric
C14: 1n; C_0402_1005Metric
C18: 22p; C_0402_1005Metric
C21, C23: 20p; C_0402_1005Metric
C30: 10u/10V; CP_EIA-3216-18_Kemet-A
C31: 10u; C_0402_1005Metric
D1, D4, D8: red; LED_0402_1005Metric
D2, D5: green; LED_0402_1005Metric
D3, D6: yellow; LED_0402_1005Metric
D7: amber; LED_0402_1005Metric
D9: blue; LED_0402_1005Metric
L1: 22n; L_0402_1005Metric
L2: 20n; L_0402_1005Metric
L3: 13n; L_0402_1005Metric
L4: 27n; L_0402_1005Metric
L5: 10u; L_0402_1005Metric
L6: 18n; L_0402_1005Metric
P1: I2C; PinHeader_1x04_P2.54mm_Vertical
P2: DISPLAY; PinHeader_1x04_P2.54mm_Vertical
P3: SMA; SMA_THT_Jack_Straight
P4: STLINK; PinHeader_1x04_P2.54mm_Vertical
PI1: RPI-ZERO; RPI-Zero-RASPBERRYPI_BASTELSTUBE_V13_RASPI_BOARD_B+_FULL
R1, R7: 10k; R_0402_1005Metric
R2: 1k1; R_0402_1005Metric
R3: 3k8; R_0402_1005Metric
R4: 3r9; R_0402_1005Metric
R5: 560; R_0402_1005Metric
R6: 270; R_0402_1005Metric
R8, R9, R10, R11, R12, R13, R14, R15, R16, R17, R18, R19: 1k; R_0402_1005Metric
R20, R21, R22: DNI; R_0402_1005Metric
SW1: DNI; SW_SPST_B3U-1000P
U1: ADF7021; QFN-48-1EP_7x7mm_Pitch0.5mm
U2: STM32F103C8T6; LQFP-48_7x7mm_Pitch0.5mm
X1: TCXO; Crystal_SMD_3225-4pin_3.2x2.5mm
Y1: 8MHz; Crystal_SMD_Abracon_ABM3-2pin_5.0x3.2mm

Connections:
+3V3: C29.1, L5.1, PI1.1, PI1.17, R20.1
+5V: P2.1, PI1.2, PI1.4
BOOT0: R1.1, U2.44
CE: U1.24, U2.3
CLKOUT: R8.1, U2.38
COS_LED: R12.2, U2.28
DATAIN: R9.1, U2.39
DATAOUT: R10.1, U2.40
DISP_RXD: P2.2, U2.13
DISP_TXD: P2.3, U2.12
DMR_LED: R15.2, U2.26
DSTAR_LED: R14.2, U2.25
GND: C1.2, C2.2, C3.2, C6.2, C7.2, C8.2, C9.2, C10.2, C12.2, C13.2, C14.2, C15.1, C16.2, C17.2, C19.2, C20.1, C21.1, C22.1, C23.1, C24.2, C25.2, C26.2, C29.2, C30.2, C31.2, D2.1, D3.1, D4.1, D5.1, D6.1, D7.1, D8.1, D9.1, P1.2, P2.4, P3.2, P4.4, PI1.6, PI1.9, PI1.14, PI1.20, PI1.25, PI1.30, PI1.34, PI1.39, R2.2, R3.2, SW1.2, U1.5, U1.12, U1.19, U1.22, U1.29, U1.45, U1.47, U1.49, U2.8, U2.20, U2.23, U2.35, U2.47, X1.2
NRST: C16.1, PI1.40, R7.1, SW1.1, U2.7
NXDN_LED: R19.2, U2.29
unnamed: AE1.1, C28.2
unnamed: C1.1, L1.2, L2.1
unnamed: C4.1, L3.1, U1.4
unnamed: C4.2, C5.2, L2.2
unnamed: C5.1, L4.2, U1.6
unnamed: C6.1, L4.1, U1.7
unnamed: C8.1, R4.2
unnamed: C10.1, U1.11
unnamed: C11.1, U1.48
unnamed: C11.2, R4.1, U1.2
unnamed: C12.1, R5.2, U1.1
unnamed: C13.1, R6.2
unnamed: C14.1, R5.1, R6.1, U1.42
unnamed: C15.2, U1.41
unnamed: C18.1, X1.3
unnamed: C18.2, U1.39
unnamed: C20.2, U1.31
unnamed: C21.2, U2.5, Y1.1
unnamed: C23.2, U2.6, Y1.2
unnamed: C27.1, P3.1
unnamed: D1.2, R18.2
unnamed: D2.2, R11.1
unnamed: D3.2, R12.1
unnamed: D4.2, R13.1
unnamed: D5.2, R14.1
unnamed: D6.2, R15.1
unnamed: D7.2, R16.1
unnamed: D8.2, R17.1
unnamed: D9.2, R19.1
unnamed: L6.1, U1.46
unnamed: L6.2, U1.44
unnamed: PI1.18, R20.2
unnamed: PI1.22, R21.2
unnamed: PI1.24, R22.2
unnamed: PI1.38, R1.2
unnamed: R2.1, U1.8
unnamed: R3.1, U1.10
unnamed: R8.2, U1.36
unnamed: R9.2, U1.35
unnamed: R10.2, U1.34
P25_LED: R17.2, U2.18
PTT_LED: R13.2, U2.27
RF: C27.2, C28.1, L1.1
RXD: PI1.8, U2.31
SCL: P1.3, PI1.5, R21.1
SCLK: U1.28, U2.41
SDA: P1.4, PI1.3, R22.1
SDATA: U1.26, U2.42
SERVICE: D1.1, U2.2
SLE: U1.25, U2.45
SREAD: U1.27, U2.43
SWCLK: P4.3, U2.37
SWDIO: P4.2, U2.34
TXD: PI1.10, U2.30
VDD: C2.1, C3.1, C7.1, C9.1, C17.1, C19.1, C22.2, C24.1, C25.1, C26.1, C30.1, C31.1, L3.2, L5.2, P1.1, P4.1, R7.2, R11.2, R18.1, U1.3, U1.9, U1.32, U1.40, U1.43, U2.1, U2.9, U2.24, U2.36, U2.48, X1.4
YSF_LED: R16.2, U2.19

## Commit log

2018-05-16 Fix ERC warnings, update pin directions on devices.
    [mmdvm_hs-hat.sch]
2018-05-16 Rotate 180° STLink connector (respect OLED and Nextion orientations). Replace GND pads to VIA (netlist can be safely updated from schematic now). Reroute Service track. Small tweaks to various tracks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
    [mmdvm_hs-hat.kicad_pcb, mmdvm_hs-hat.sch]
2018-05-16 Packages has been updated to latest KiCAD (daily) naming scheme, with few execptions. Rotate 180° STLink connector (respect OLED and Nextion orientations). Replace GND pads to VIA (netlist can be saf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
    [mmdvm_hs-hat.kicad_pcb, mmdvm_hs-hat.sch]
2018-05-17 Add ceramic antenna and LED 3d step files.
    [mmdvm_hs-hat.kicad_pcb]
2018-05-17 A bit of reorg. 3D shapes in their own packages3d/subdir.
    [mmdvm_hs-hat.kicad_pcb]
2018-05-17 Few track re-routed, few components moved. SMA sligthly moved to get better GND one for corners. Center tracks in 2x20 connector.
    [mmdvm_hs-hat.kicad_pcb]
2018-05-18 Add a wearning about KiCAD 5.
2018-05-18 KiCAD -> KiCad.
2018-05-28 Update the BOM.
    [BOM.csv, BOM.xlsx]
2018-05-29 Add I2C OLED on 2x20 connector (should make it optional).
    [mmdvm_hs-hat.kicad_pcb, mmdvm_hs-hat.sch]
2018-05-30 Make OLED_on_2x20 optionnal, electrically (using 3x0402 unpopulated resistors).
    [mmdvm_hs-hat.kicad_pcb, mmdvm_hs-hat.sch]
2018-05-30 Fine tunning some tracks.
    [mmdvm_hs-hat.kicad_pcb]
2018-06-06 Fix DRC's fiducial warning.
    [mmdvm_hs-hat.kicad_pcb]
2018-06-08 Updated Gerber files for r1.7.
    [mmdvm_hs-hat-B.Cu.gbl, mmdvm_hs-hat-B.Mask.gbs, mmdvm_hs-hat-B.Paste.gbp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]
2018-06-08 Last silkscreen changes for this release.
    [mmdvm_hs-hat.kicad_pcb]
2018-06-16 Update enclosures informations in the README, mention my enclosures.
